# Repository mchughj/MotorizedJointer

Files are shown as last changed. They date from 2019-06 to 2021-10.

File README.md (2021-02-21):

# MotorizedJointer

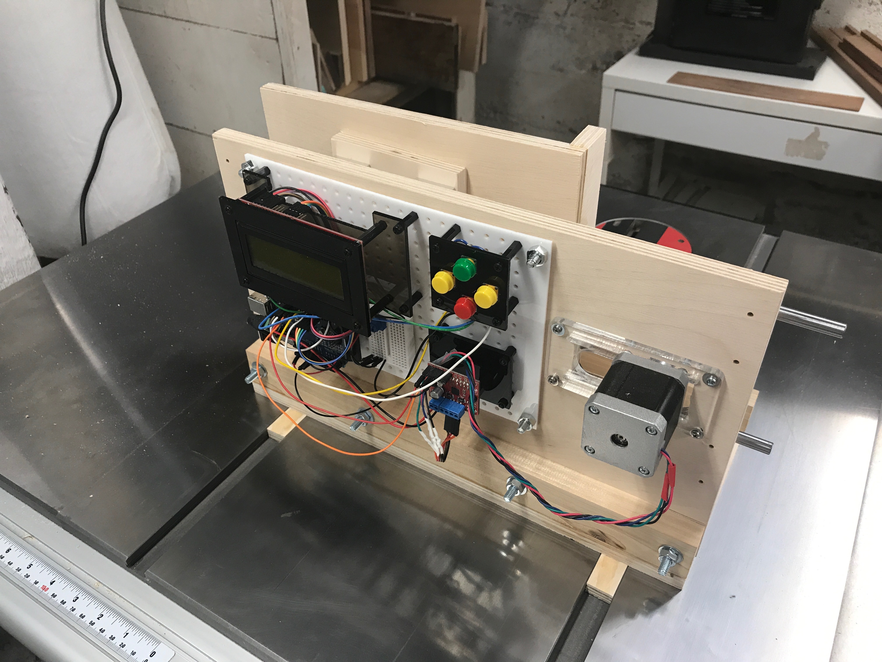
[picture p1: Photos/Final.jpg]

(Yes, wire management is not my strong suit.  But it works!)

This is a project which I started in 2017 after seeing a YouTube video on something similar.  

The main software appears in the CustomizableBoxCutter directory.

Hardware
 * A sparkfun "Basic 20x4 Character LCD - Black on Green 5V".  This is an HD47780-based display.  Retired version here: https://www.sparkfun.com/products/retired/256  
 * A Nema 17 stepper motor.  Example: https://www.sparkfun.com/products/9238  
 * A driver for the stepper motor.  I used a Big Easy Driver: https://www.sparkfun.com/products/12859
 * An arduino Uno.  Any Uno will do.
 * Four small buttons.  These will work: https://www.sparkfun.com/products/14460

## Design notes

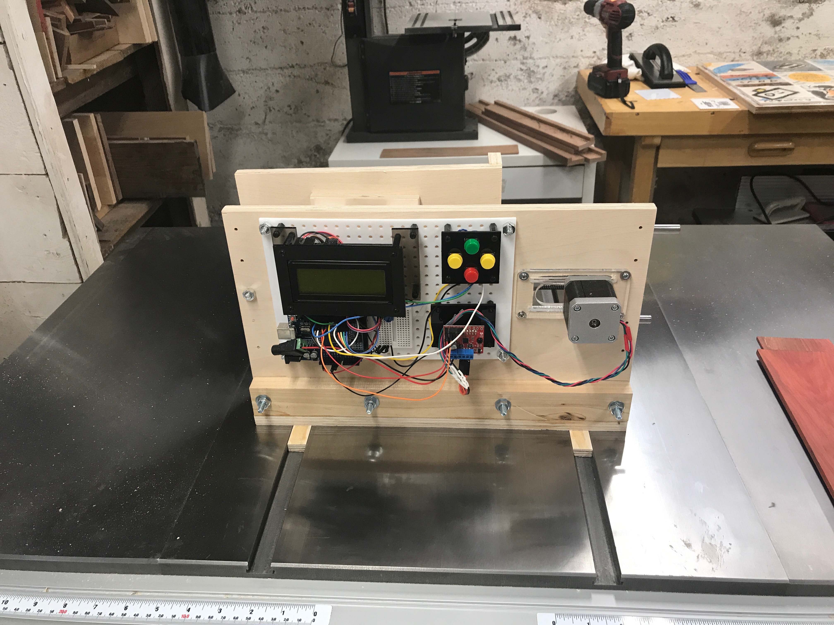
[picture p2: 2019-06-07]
Photos/BackView.jpg

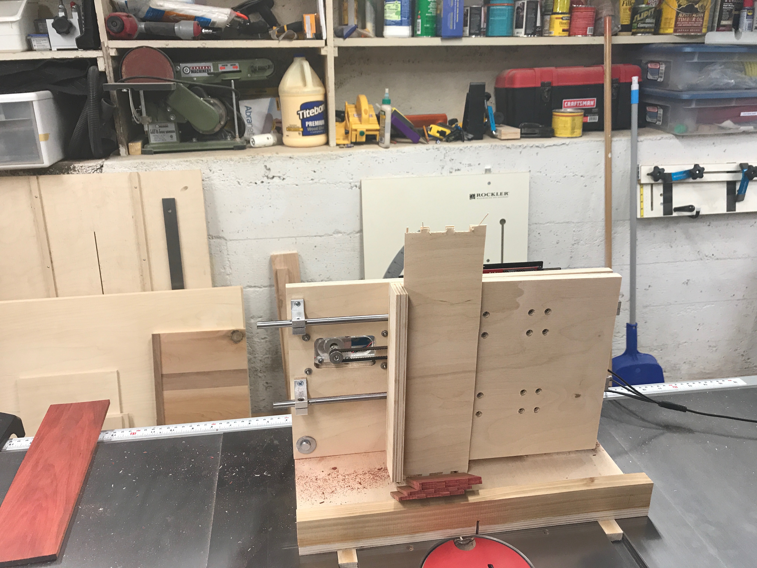
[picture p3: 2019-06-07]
Photos/FirstCuts.jpg

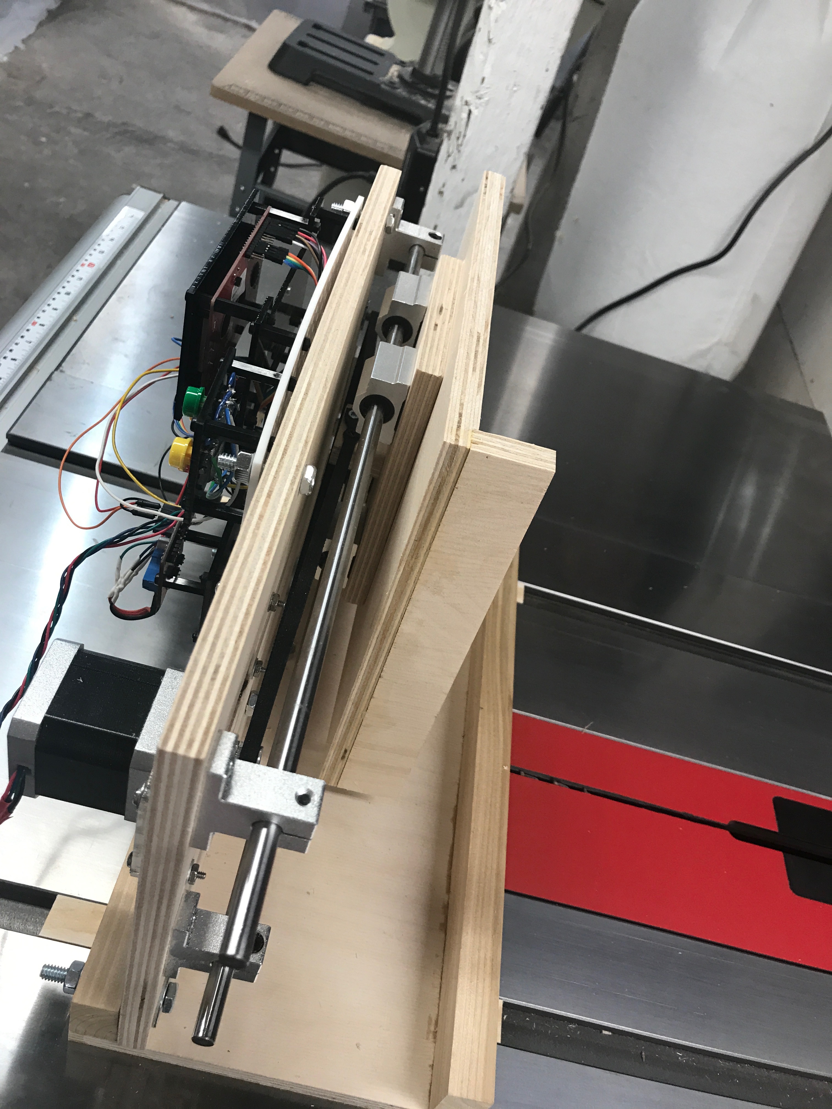
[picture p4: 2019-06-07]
Photos/SideView.jpg

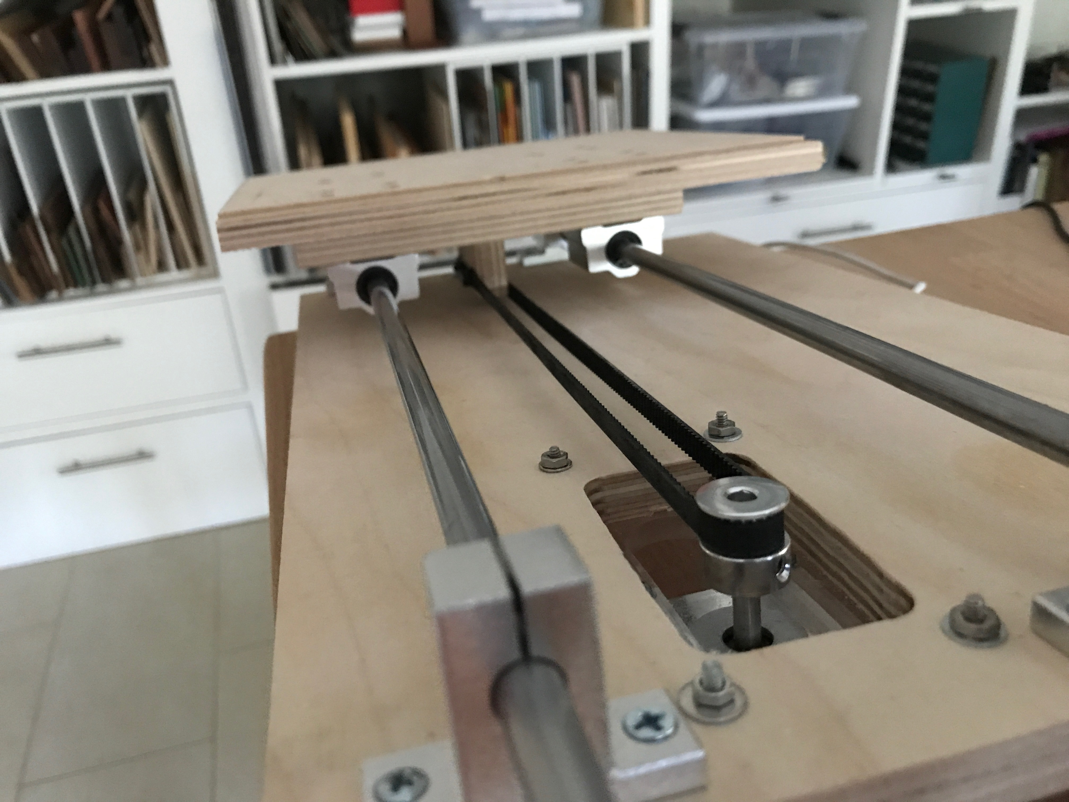
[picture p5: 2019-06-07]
Photos/Gantry.jpg

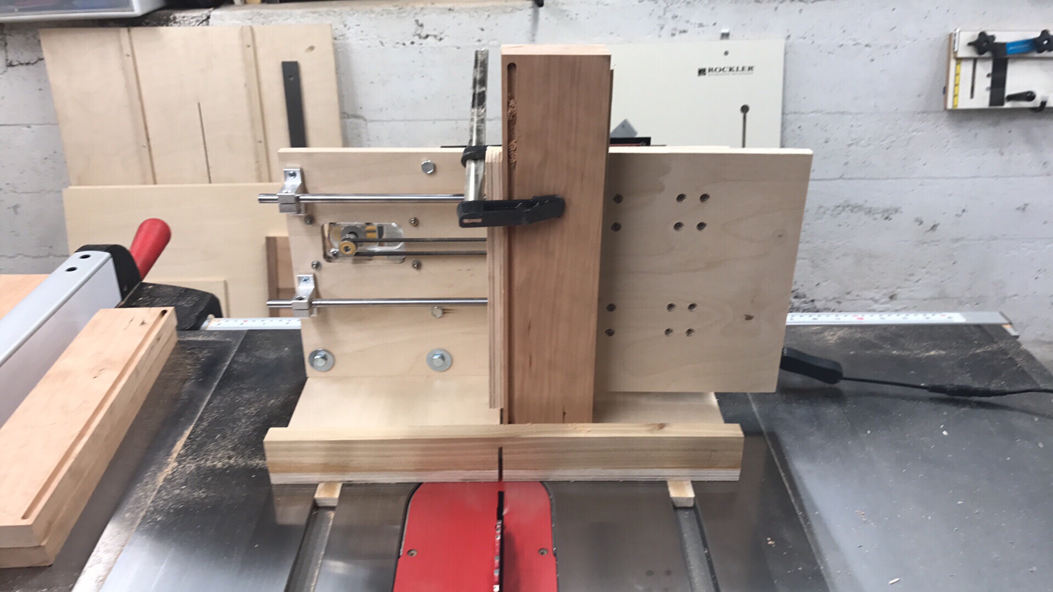
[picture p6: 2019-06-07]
Photos/LongCut.jpg

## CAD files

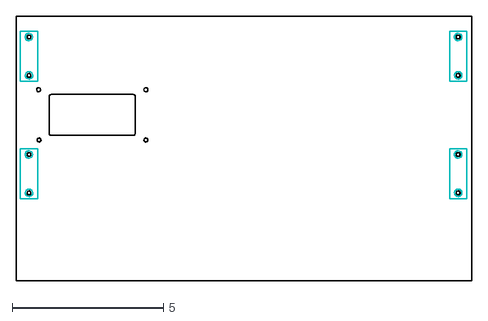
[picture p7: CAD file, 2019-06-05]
Hardware/Rails.dxf
15.0 x 8.75

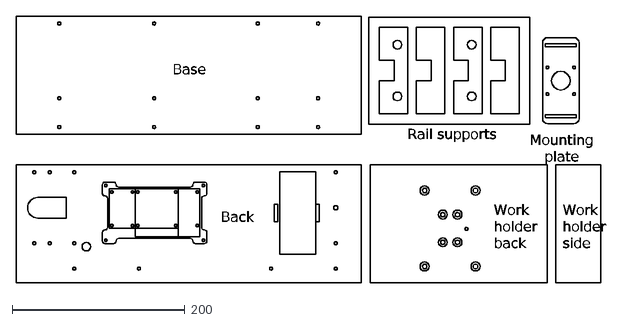
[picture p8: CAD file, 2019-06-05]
Hardware/sj_ply_manual.dxf
Work holder back
Rail supports
Work holder side
Base
Back
Mounting plate

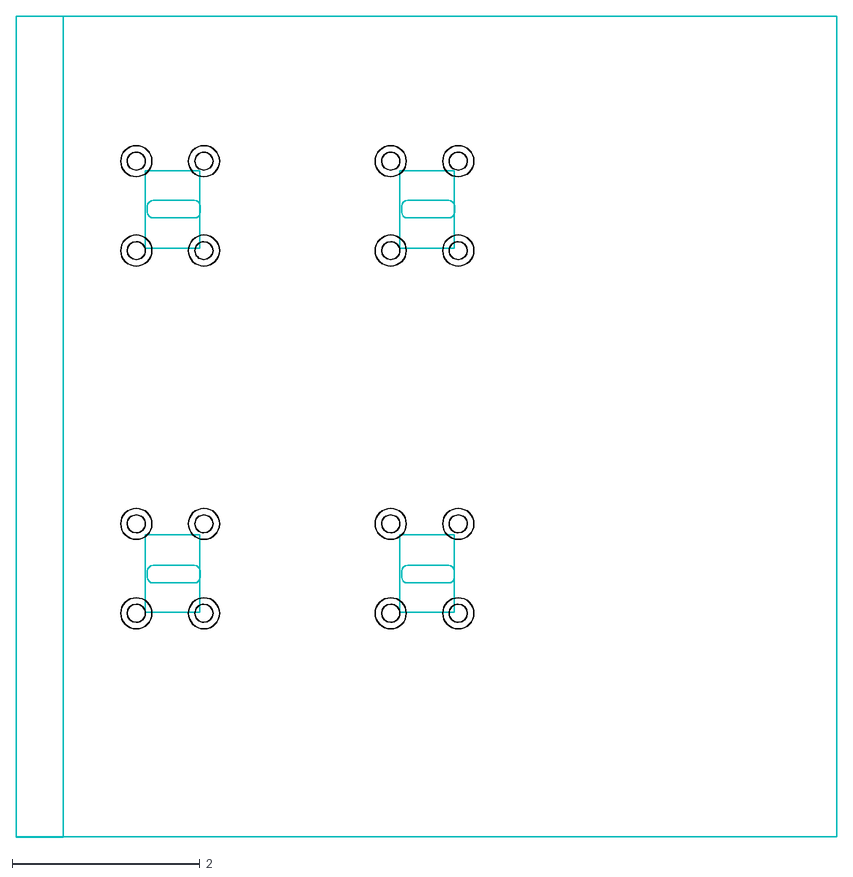
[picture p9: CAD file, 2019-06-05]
Hardware/Gantry.dxf
8.75 x 8.75

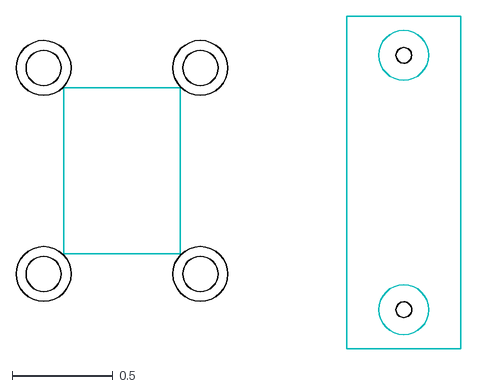
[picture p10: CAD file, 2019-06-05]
Hardware/LinearBearing.dxf
2.21 x 1.65

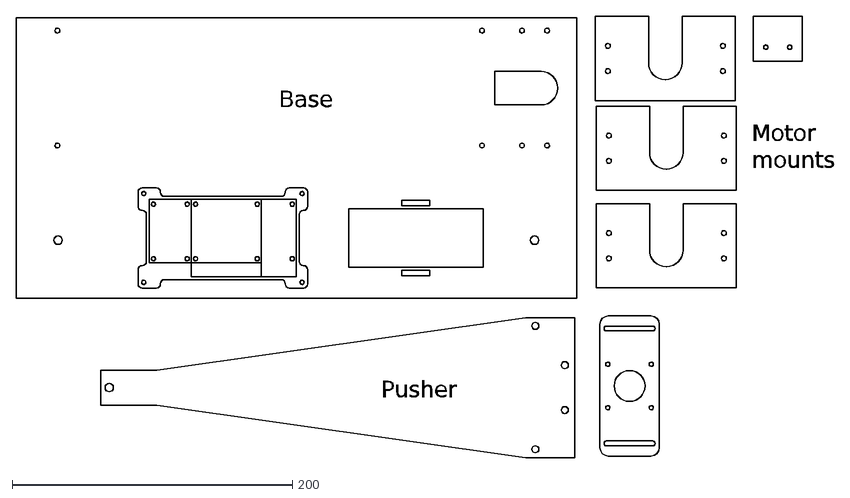
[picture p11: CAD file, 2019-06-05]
Hardware/sj_pusher.dxf
Base
Pusher
Motor mounts

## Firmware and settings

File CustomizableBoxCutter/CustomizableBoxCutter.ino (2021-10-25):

// This embedded program drives the behavior of the customizable box cutter.  
// This derives from, and expands up, the original 'simple box cutter'.
//
// 6/30/2019: First version

// Hardware:
// 1/  A sparkfun "Basic 20x4 Character LCD - Black on Green 5V".  This is
//     an HD47780-based display.  
// 2/  A Nema 17 stepper motor.  https://www.sparkfun.com/products/9238  
// 3/  A Big Easy Driver.  https://www.sparkfun.com/products/12859

// LCD Pins:
//
// LCD RS pin to digital pin 12
// LCD Enable pin to digital pin 11
// LCD D4 pin to digital pin 5
// LCD D5 pin to digital pin 4
// LCD D6 pin to digital pin 3
// LCD D7 pin to digital pin 2
// LCD R/W pin to ground
// LCD VSS pin to ground
// LCD VCC pin to 5V
// 
// Input pins:
//   6  - Left button
//   7  - Right button
//   8  - Center button
//
// Stepper Pins:
//   9  - Step
//   10 - Direction
//


// --------------------------------------------------------------------------
// Understanding the finger & valley goodness
// --------------------------------------------------------------------------

// This documentation is broken up into three sections where each 
// subsequent section builds on the prior and introduces some complexity
// that was glossed over in the prior section.  This aids in understanding
// what is happening into smaller sized chunks.
//
// Section 1:  Fingers & Valleys
// Section 2:  Initial cuts versus subsequent cuts
// Section 3:  Non-uniform sized cuts


// --------------------------------------------------------------------------
// Section 1:  Fingers & Valleys
// --------------------------------------------------------------------------

//
//  The Finger Joints look like this:
//
//        "Negative"              "Positive"
//    isCutFirst = False      isCutFirst = True
//    +------------------+    +---------------+
//    |     WOOD         |    |     WOOD      |
//    |                  |    |               |
//    |    [Finger]      |    |   [Valley]    |
//    |                  |    |               |
//    |          +-------+    |               |
//    |          |    +-------+               |
//    |          |    |                       |
//    | [Valley] |    |           [Finger]    |
//    |          |    |                       |
//    |          |    +-------+               |
//    |          +-------+    |               |
//    |                  |    |               |
//        ... 
//
// There are 2 values in use when you are doing a pair of Finger and Valley. 
// The first is how much to cut - this is the size of the valley.  The second
// is the amount to move giving you the size of the finger.
// The valley needs to be larger than the finger by just a little bit.
// If they were the exact same size then they would be too tight. 
// Depending on the material and the characteristics of the cutting, a few
// thousands of an inch should be sufficient.  This parameter (the additional
// thousandths of an inch to cut to allow them to fit) is called 'slop'.
//
// The units for all variables that are capturing distance are in thousandths
// of an inch.  So 500 is 0.5 inches.

// The menu on the device talks about "Positive" and "Negative" for the two
// mating pieces of wood. 
// 
//  When "Positive" then isCutFirst = True - which means we cut then move:
//    distanceRemainingToCut = initialDTMValley;
//    distanceRemainingToMove = subDTMFinger;
//

//
//  When "Negative" then isCutFirst = False - which means that we just move:
//    distanceRemainingToCut = 0;
//    distanceRemainingToMove = initialDTMFinger;
//



// --------------------------------------------------------------------------
// Section 2:  Initial cuts versus subsequent cuts
// --------------------------------------------------------------------------

// Positive and negative cuts are all good but how do we make the entire
// process repeatable given that we don't want to create an initial setup 
// that is simple and doesn't require any guess work on where to start?
//

// The jig is operated by the following steps:
//   0/  Clamp the wood into the gantry.  Make sure it is flush and square.
//   1/  Move the gantry (not the wood) so that the wood is flush against 
//       the table saw.
//   2/  Select the cut type, turn on the table saw.
// 
//   3/  Push the jig forward, then back.
//   4/  Hit the next button (on the right) on the jig.
//   5/  Goto step 2.
//  
// This keeps the process simple and repeatable.  Two important characteristics
// when moving wood over-and-over through a spinning blade!!
// 

// But this also complicates the software as we need to get the movement and
// cut values correct given that there are two situations.  This is because on
// the very first finger/valley the blade is to the left of where the wood is.
// To start the wood is put flush against the blade and, when we push the jig
// through the blade (step #3), empty air is cut.  The setup looks like this:
//
//  
//            B                             ^      
//            L                             |
//            A                             |
//       ----+D                        Human Pushes
//           |E                          the jig
//           |                              |
//           |                              |
//
//   -> Stepper movement ->
// 
// When you push the jig forward, and move the blade through the wood, 
// no wood is actually cut since the initial setup has the blade flush against
// the wood.
//

// This requires the 'initial' finger (or valley) to differ from all others
// because the kerf distance needs to be taken into account.
//
// For the first finger/valley, the variables 'initialDTMFinger' or
// 'initialDTMValley' are used.  DTM stands for 'distance to move'.  
//
//    initialDTMValley  =  valleySize     +  slop         +  0;  
//    initialDTMFinger  =  fingerSize     +  -slop        +  kerf;  
//
// Because step #3 doesn't actually do anything (you cut empty air the first
// time) the initial distance to cut includes the full slot and slop.  The zero
// term there will make sense once you see the subDTMValley for non-initial
// finger/valleys.
//
// The initialDTMFinger is offset by the kerf term in order to position
// the cutter inside of the wood for the next step.

// 
// After that first initial finger or valley the blade is ready to pass through
// material into the valley of the second and all subsequent joints.  This is
// because when doing a negative cut we don't do anything but move to the
// starting point of the first valley.  When doing positive then we cut and
// then do a big move.  In both cases we are ready to pass the material through
// the blade as part of the subsequent valley.
//
// In this case the setup looks like this:
//  
//                -> Stepper movement ->
// 
//            B                           B              
//            L                           L                      ^ 
//            A                           A                      | 
//            D                           D                      | 
//            E              OR           E                 Human Pushes
//      +--------                   +-----------              the jig
//      |                           |                            |
//      |                           |                            |
//  +---+                           |             
//  |                               |         
//   
//
// Now step #3 will *not* cut empty air.  It will cut a kerf amount of wood.  
// Therefore all subsequent valley and finger distance to moves are 
// defined by:
//  
//    subDTMValley  = valleySize     +  slop         -  kerf;  
//    subDTMFinger  = fingerSize     +  -slop        +  kerf;
// 
// The term 'sub' is short for subsequent which captures all fingers and
// valleys after the first.


// --------------------------------------------------------------------------
// Section 3:  Non-uniform sized cuts
// --------------------------------------------------------------------------
//
// Final complication!  When you are doing the same sized fingers and 
// valleys then the process is simple.  When doing variable sized fingers
// and valleys the conceptual is still the same but the details are a
// bit more tricky.  
//                                              
// When doing the programmatic cut you set the individual stop points for
// each of the fingers or valleys.  Whether the stop point represents a 
// finger or valley depends upon whether you are doing the positive or
// negative piece.
//
// The numeric values shown below are the thous that have been set up 
// while programming.  
// 
//        Negative              Positive
//    +-----------------+    +---------------+
//    |                 |    |               |
//    | 200             |    |    200        |
//    |     Wood        |    |               |
//    |                 |    |               |
//    |         +-------+    |               |
//    |         |    +-------+               |
//    | 300     |    |                       |
//    |         |    |            300        |
//    |         |    |                       |
//    |         |    +-------+               |
//    |         +-------+    |               |
//    |                 |    |               |
//    |                 |    |               |
//    |                 |    |               |
//    | 500             |    |   500         |
//    |                 |    |               |
//    |                 |    |               |
//    |         +-------+    |               |
//    |         |    +-------+               |
//    | 300     |    |                       |
//    |         |    |           300         |
//    |         |    |                       |
//    |         |    +-------+               |
//    |         +-------+    |               |
//    |                 |    |               |
//    |                 |    |               |
//    | 200             |    |   200         |
//    |                 |    |               |
//    +-----------------+    +---------------+
// 
// In the example above the programmaticSlots would look like:
//  programmaticSlots[] = {
//     200,
//     300,
//     500,
//     300,
//     200,
//     0, 0, 0, ..., 0,
//  }
// 
// When doing the positive we would pass in 
//  valley = 200 (programmaticSlot[0]), finger = 300 (programmaticSlots[1])
//  valley = 500 (programmaticSlot[2]), finger = 300 (programmaticSlots[3])
//  valley = 200 (programmaticSlot[4]), finger = 200 (programmaticSlots[0])
//    (If the end of the piece of wood is reached before wrapping around 
//       then the wrap around doesn't matter.)
// 
// When doing the negative we would pass in 
//  valley = 0 (no programmaticSlot!),  finger = 200 (programmaticSlots[0])
//  valley = 300 (programmaticSlot[1]), finger = 500 (programmaticSlots[2])
//  valley = 300 (programmaticSlot[3]), finger = 200 (programmaticSlots[4])
//
// Thus the movement through the programmaticSlots is always by 2s for 
// a single valley and finger pair, but it is offset by one when 
// doing the negative.  

 
#include <LiquidCrystal.h>
#include <EEPROM.h>   

#define BUTTON_LEFT_PIN 6
#define BUTTON_RIGHT_PIN 7
#define BUTTON_DOWN_PIN 8
#define BUTTON_UP_PIN 13
#define STEP_PIN 10
#define DIRECTION_PIN 9
#define MOTOR_ENABLE_PIN A0
#define MOTOR_MS1_PIN A3
#define MOTOR_MS2_PIN A4
#define MOTOR_MS3_PIN A5

// All units are in thousands of an inch.
// So, for example, 125 = 0.125"

// Default kerf size of blade
uint16_t kerf = 123;

// Default movement can be less than the kerf of the blade if you want overlapping cuts.
uint16_t maxAdvance = 100;

#define MAX_PROGRAMMATIC_SLOTS 64
uint16_t uniformSlot;
uint16_t programmaticSlots[MAX_PROGRAMMATIC_SLOTS] = {
       125, 125, 125, 125, 125, 125, 125, 125,
       125, 125, 125, 125, 125, 125, 125, 125,
       125, 125, 125, 125, 125, 125, 125, 125,
       125, 125, 125, 125, 125, 125, 125, 125,
       0,   0,   0,   0,   0,   0,   0,   0,
       0,   0,   0,   0,   0,   0,   0,   0,
       0,   0,   0,   0,   0,   0,   0,   0,
       0,   0,   0,   0,   0,   0,   0,   0,
};
uint16_t programmaticIndex = 0;
uint16_t slop = 1;

// Computed based on the current options.  Set in determineMovementValues.
// DTM == Distance To Move.
uint16_t initialDTMValley;
uint16_t initialDTMFinger;
uint16_t subDTMValley;
uint16_t subDTMFinger;

uint16_t currentFingerSize;
uint16_t currentValleySize;

uint16_t distanceRemainingToCut = 0;
uint16_t distanceRemainingToMove = 0;

// Default speed for movement.  This is in microseconds and captures the amount of time
// to wait inbetween low and high pulses.  A larger number indicates slower speed.
uint16_t motorSpeed = 500;

// Default length of wood and number of slots.
uint32_t lengthOfWood = 4000;
uint16_t numberOfSlots = 6;

// Initialize the LCD.  Pin numbers in the below match the earlier comments.
LiquidCrystal lcd(12, 11, 5, 4, 3, 2);

// Creating characters for display is pretty straightforward.
// Use this site:  http://www.quinapalus.com/hd44780udg.html
// for all of the heavy lifting.
byte thumbUpIcon[6][8] = {
 {B00100,B00011,B00100,B00011,B00100,B00011,B00010,B00001},
 {B00000,B00000,B00000,B00000,B00000,B00000,B00000,B00011},
 {B00000,B00000,B00000,B00000,B00000,B00000,B00001,B11110},
 {B00000,B01100,B10010,B10010,B10001,B01000,B11110,B00000},
 {B00010,B00010,B00010,B00010,B00010,B01110,B10000,B00000},
 {B00000,B00000,B00000,B00000,B00000,B10000,B01000,B00110}
};

#define MAIN_MENU 0
#define CUT_MENU 1
#define CONFIG_MENU 3
#define CONFIG_CHANGE_VALUE_MENU 4
#define UNIFORM_CUT_MENU 5
#define PROGRAMMATIC_CUT_MENU 6
#define CUT_TYPE_MENU 7

void registerThumbUp() { 
  for( int i=0; i < 6; i++ ) { 
    lcd.createChar(i, thumbUpIcon[i]);
  }
}

bool isLeftButtonPressed() {
  return digitalRead( BUTTON_LEFT_PIN ) == LOW;
}

bool isRightButtonPressed() {
  return digitalRead( BUTTON_RIGHT_PIN ) == LOW;
}

bool isDownButtonPressed() {
  return digitalRead( BUTTON_DOWN_PIN ) == LOW;
}

bool isUpButtonPressed() {
  return digitalRead( BUTTON_UP_PIN ) == LOW;
}

void waitForButtonRelease(uint8_t pin) { 
  delay(50);
  while( digitalRead(pin) == LOW ) { 
    delay(1);
  }
  delay(40);
}
void waitForLeftButtonRelease() {
  waitForButtonRelease(BUTTON_LEFT_PIN);
}

void waitForDownButtonRelease() {
  waitForButtonRelease(BUTTON_DOWN_PIN);
}

void waitForRightButtonRelease() {
  waitForButtonRelease(BUTTON_RIGHT_PIN);
}

void waitForUpButtonRelease() {
  waitForButtonRelease(BUTTON_UP_PIN);
}

void motorOn() {
  digitalWrite(MOTOR_ENABLE_PIN, LOW); 
}

void motorOff() {
  digitalWrite(MOTOR_ENABLE_PIN, HIGH);
}

void stepMotor(uint16_t d = motorSpeed) { 
  digitalWrite(STEP_PIN, HIGH);
  delayMicroseconds(d);
  digitalWrite(STEP_PIN, LOW);
  delayMicroseconds(d);
}

bool moveStepper(uint16_t thousDistance, bool isLeft) { 
  if( isLeft ) { 
    digitalWrite(DIRECTION_PIN, LOW);
  } else {
    digitalWrite(DIRECTION_PIN, HIGH);
  }

  // The number of steps per thousandths of an inch
  float stepsPerThou = 4.19;
  unsigned long int numberOfSteps = ceil(( ( (unsigned long int) thousDistance) * stepsPerThou ));
  Serial.print(F("moveStepper; inches: " ));
  Serial.print(thousDistance);
  Serial.print(F(", isLeft: " ));
  Serial.print(isLeft);
  Serial.print(F(", numberOfSteps: " ));
  Serial.println(numberOfSteps);
  for( unsigned long int i = 0; i < numberOfSteps; i++ ) { 
    stepMotor();
  }
  return true;
}

void drawThumbUp() { 
  lcd.setCursor(16,3);
  lcd.write((uint8_t)0);
  lcd.setCursor(16,2);
  lcd.write((uint8_t)1);
  lcd.setCursor(17,3);
  lcd.write((uint8_t)2);
  lcd.setCursor(17,2);
  lcd.write((uint8_t)3);
  lcd.setCursor(18,3);
  lcd.write((uint8_t)4);
  lcd.setCursor(18,2);
  lcd.write((uint8_t)5);
}

void writeSettings() {
  uint8_t kerfInByte = (uint8_t) kerf;

  Serial.print( F("going to writeSettings; kerf: "));
  Serial.print(kerf);
  Serial.print( F(", motorSpeed: "));
  Serial.print(motorSpeed);
  Serial.print( F(", slop: "));
  Serial.print(slop);
  Serial.print( F(", lengthOfWood: "));
  Serial.print(lengthOfWood);
  Serial.print( F(", numberOfSlots: "));
  Serial.print(numberOfSlots);
  Serial.print( F(", maxAdvance: "));
  Serial.print(maxAdvance);
  Serial.print( F(", uniformSlot: "));
  Serial.println(uniformSlot);
  
  EEPROM.write(0, byte(215));
  EEPROM.write(1, byte(kerf));
  EEPROM.write(2, byte(motorSpeed / 256));
  EEPROM.write(3, byte(motorSpeed % 256));
  EEPROM.write(4, byte(slop / 256));
  EEPROM.write(5, byte(slop % 256));

  EEPROM.put(6, lengthOfWood);

  EEPROM.write(10, byte(numberOfSlots / 256));
  EEPROM.write(11, byte(numberOfSlots % 256));

  EEPROM.write(12, byte(maxAdvance));

  EEPROM.write(13, byte(uniformSlot / 256));
  EEPROM.write(14, byte(uniformSlot % 256));

  for( int i=0; i < MAX_PROGRAMMATIC_SLOTS; i++ ) { 
    EEPROM.write(15 + (i*2), byte(programmaticSlots[i] / 256));
    EEPROM.write(16 + (i*2), byte(programmaticSlots[i] % 256));
  }

  Serial.print( F("Programmatic slots, maxLength: "));
  Serial.print( MAX_PROGRAMMATIC_SLOTS );
  for( int i=0; i < MAX_PROGRAMMATIC_SLOTS; i++ ) { 
    Serial.print( F(", S" ));
    Serial.print( i );
    Serial.print( F(": "));
    Serial.print(programmaticSlots[i]);
  }
  Serial.println( F("!"));

  lcd.setCursor(1, 1);
  lcd.print("Saved settings");
  delay(1000);
}

void determineMovementValues( uint16_t valleySize, uint16_t fingerSize ) {
  // Put the valley and finger sizes in a global variable for the 
  // display to easily access.
  currentValleySize = valleySize;
  currentFingerSize = fingerSize;

  // See comments at the top of the file.
  initialDTMValley  =  valleySize   +  slop    + 0;  
  initialDTMFinger  =  fingerSize   + -slop    + kerf; 

  subDTMValley      =  valleySize   +  slop    + -kerf;
  subDTMFinger      =  fingerSize   + -slop    + kerf;
}


void readSettings() {
  byte kerfByte = EEPROM.read(1);
  kerf = kerfByte;
  
  motorSpeed = (EEPROM.read(2) * 256) + EEPROM.read(3);
  slop = (EEPROM.read(4) * 256) + EEPROM.read(5);

  EEPROM.get(6, lengthOfWood);

  numberOfSlots = (EEPROM.read(10) * 256) + EEPROM.read(11);

  byte maxAdvanceByte = EEPROM.read(12);
  maxAdvance = maxAdvanceByte;

  uniformSlot = (EEPROM.read(13) * 256) + EEPROM.read(14);

  for( int i=0; i < MAX_PROGRAMMATIC_SLOTS; i++ ) { 
    uint16_t s = (EEPROM.read(15 + (i * 2)) * 256) + EEPROM.read(16 + (i*2));
    programmaticSlots[i] = s;
  }

  Serial.print( F("read in the settings; kerf: "));
  Serial.print(kerf);
  Serial.print( F(", motorSpeed: "));
  Serial.print(motorSpeed);
  Serial.print( F(", slop: "));
  Serial.print(slop);
  Serial.print( F(", lengthOfWood: "));
  Serial.print(lengthOfWood);
  Serial.print( F(", numberOfSlots: "));
  Serial.print(numberOfSlots);
  Serial.print( F(", maxAdvance: "));
  Serial.print(maxAdvance);
  Serial.print( F(", uniformSlot: "));
  Serial.print(uniformSlot);

  for( int i=0; i < MAX_PROGRAMMATIC_SLOTS; i++ ) { 
    Serial.print( F(", S" ));
    Serial.print( i );
    Serial.print( F(": "));
    Serial.print(programmaticSlots[i]);
  }
  Serial.println("!");
}


void setup() {
  Serial.begin(9600);
  Serial.println("In setup");
  Serial.println( __DATE__ " " __TIME__ );
  pinMode( STEP_PIN, OUTPUT );
  pinMode( DIRECTION_PIN, OUTPUT ); 
  
  pinMode( BUTTON_LEFT_PIN, INPUT_PULLUP );
  pinMode( BUTTON_RIGHT_PIN, INPUT_PULLUP );
  pinMode( BUTTON_DOWN_PIN, INPUT_PULLUP );
  pinMode( BUTTON_UP_PIN, INPUT_PULLUP );

  pinMode( MOTOR_ENABLE_PIN, OUTPUT );

  pinMode( MOTOR_MS1_PIN, OUTPUT);
  pinMode( MOTOR_MS2_PIN, OUTPUT);
  pinMode( MOTOR_MS3_PIN, OUTPUT);
  digitalWrite( MOTOR_MS1_PIN, HIGH ); 
  digitalWrite( MOTOR_MS2_PIN, HIGH );
  digitalWrite( MOTOR_MS3_PIN, HIGH );
  
  lcd.begin(20, 4);
  registerThumbUp();

  // If the eeprom on the arduino doesn't have settings stored there or
  // if you hold the up button when you turn on the unit, then we write 
  // the default values.
  if (EEPROM.read(0) != 215 || isUpButtonPressed()) { 
    Serial.println("Writing configuration setup");
    writeSettings(); 
    readSettings();
  } else {
    Serial.println("Reading configuration setup");
    readSettings();
  }
  Serial.println("Done with setup");
}

void showOptions(const char *left, const char *bottom, const char *right = NULL, const char *top = NULL, const int startLine = 1) { 
  char statusMessage[16];

  if( top ) { 
    showCentered(top, startLine);
  }
  if( left ) {
    snprintf(statusMessage, 16, "%s", left);
    lcd.setCursor(0, startLine+1);
    lcd.print(statusMessage);
  }
  if( right ) {
    showRightAligned(right, startLine+1);
  }
  if( bottom ) {
    showCentered(bottom, startLine+2);
  }
}

int state = 0;
bool isUniformCut = true;
int pos = 0;
bool refreshDisplay = true;

bool isCutFirst = true;

void setupForCut( bool cutFirst ) {
  motorOn();

  isCutFirst = cutFirst;
  
  if( isCutFirst ) { 
    distanceRemainingToCut = initialDTMValley;
    distanceRemainingToMove = subDTMFinger;
  } else {
    distanceRemainingToCut = 0;
    distanceRemainingToMove = initialDTMFinger;
  }
}
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
void loop() {
  if (state == MAIN_MENU) { 
    showMainMenu();
  } else if (state == CUT_MENU) {     
    showCutMenu();
  } else if (state == CONFIG_MENU) {
    showConfigMenu();
  } else if (state == CONFIG_CHANGE_VALUE_MENU) {
    showConfigChangeValueMenu();
  } else if (state == CUT_TYPE_MENU) {
    showCutTypeMenu();
  }
}

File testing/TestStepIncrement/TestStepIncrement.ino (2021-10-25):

//
// 10/22/2021
//
// After questioning the accuracy of the jig in terms of distance
// moved I decided to make a more robust measurement of the 
// distance traveled.  I also wanted to make sure that I was moving
// the smallest possible distance with every pulse.  As it turns
// out though the Sparkfun "Big Easy Driver" defaults to 1/16th steps
// when you don't access the MS1, MS2 and MS3 pins.  (They are 
// all tied high by default.)
//
// Using a Dial Indicator (https://www.amazon.com/gp/product/B002YPHT76/)
// I measured the precise thousands of an inch that the device
// moved over multiple distances to get - as close as I could determine -
// the number of steps required to move one thousandth of an inch.
//
// This script assumes you are using the big easy driver by sparkfun:
// https://www.sparkfun.com/products/12859
//


#define STEP_PIN 10
#define DIRECTION_PIN 9
#define ENABLE_PIN A0
#define MS1 A3
#define MS2 A4
#define MS3 A5

uint16_t motorSpeed = 500;
bool enabled = true;


void stepMotor(uint16_t d = motorSpeed) { 
  digitalWrite(STEP_PIN, HIGH);
  delayMicroseconds(d);
  digitalWrite(STEP_PIN, LOW);
  delayMicroseconds(d);
}

void moveStepper(int numberOfSteps, int directionValue = LOW, int ms1Value = LOW, int ms2Value = LOW, int ms3Value = LOW) {
  digitalWrite(MS1, ms1Value);
  digitalWrite(MS2, ms2Value);
  digitalWrite(MS3, ms3Value);
  digitalWrite(DIRECTION_PIN, directionValue);
  
  for( int i = 0; i < numberOfSteps; i++ ) { 
    stepMotor();
 }
}

int thousToSteps(int thous) { 
   float steps = thous * 4.19;
   
   return ceil(steps);
}

void resetMotorPins()
{
  digitalWrite(STEP_PIN, LOW);
  digitalWrite(DIRECTION_PIN, LOW);
  digitalWrite(MS1, LOW);
  digitalWrite(MS2, LOW);
  digitalWrite(MS3, LOW);

  if (enabled) { 
    digitalWrite(ENABLE_PIN, LOW);
  } else {
    digitalWrite(ENABLE_PIN, HIGH);
  }
}

void setup() {
  Serial.begin(9600);
  Serial.println("In setup");
  Serial.println( __DATE__ " " __TIME__ );
  pinMode(STEP_PIN, OUTPUT );
  pinMode(DIRECTION_PIN, OUTPUT); 
  pinMode(MS1, OUTPUT);
  pinMode(MS2, OUTPUT);
  pinMode(MS3, OUTPUT);
  pinMode(ENABLE_PIN, OUTPUT);

  resetMotorPins(); 
  
  Serial.println("Begin motor test");
  Serial.println();
  //Print function list for user selection
  Serial.println("Enter number for control option:");
  Serial.println("1. Turn at 1/8th microstep mode.");
  Serial.println("2. Reverse direction at 1/8th microstep mode.");
  Serial.println("3. Turn at 1/16th microstep mode.");
  Serial.println("4. Reverse turn at 1/16th microstep mode.");
  Serial.println("5. Toggle enable of motor.");
  Serial.println("6. Move forward 0.25 inches");
  Serial.println("7. Move backwards 0.25 inches");
  Serial.println("8. Increase distance to travel.");
  Serial.println("9. Decrease distance to travel.");
  Serial.println();
}

int distance_to_move = 500;

// 500 is 0.17"

void loop() {
  int available;
  while(available = Serial.available()) {
      Serial.print( "Bytes waiting for me: ");
      Serial.println(available);
      char user_input = Serial.read(); //Read user input and trigger appropriate function

      if (available > 1) {
        int additional = 1;
        while (additional < available) { 
          Serial.print( "Additional data: ");
          Serial.println( Serial.read());
          additional += 1; 
        }
      }
      
      if (user_input =='1')
      {
         Serial.println( "Moving stepper forward 1/8th step");
         moveStepper(distance_to_move, LOW, HIGH, HIGH, LOW);

         if (!enabled) { 
           Serial.println( "Enable is off; suppressing action." );
         }
      }
      else if(user_input =='2')
      {
         Serial.println( "Moving stepper backward 1/8th step");
         moveStepper(distance_to_move, HIGH, HIGH, LOW, LOW);
         
         if (!enabled) { 
           Serial.println( "Enable is off; suppressing action." );
         }
      }
      else if(user_input =='3')
      {
          Serial.println( "Moving stepper forward 1/16th step");
          moveStepper(distance_to_move, LOW, HIGH, HIGH, HIGH);         
          if (!enabled) { 
            Serial.println( "Enable is off; suppressing action." );
          }
      }
      else if(user_input =='4')
      {
          Serial.println( "Moving stepper backward 1/16th step");
          moveStepper(distance_to_move, HIGH, HIGH, HIGH, HIGH);         
          if (!enabled) { 
           Serial.println( "Enable is off; suppressing action." );
         }
      }
      else if(user_input == '5') 
      {
         Serial.print( "Changing enabled pin;  motors active: ");
         enabled = !enabled;
         if (enabled) { 
            Serial.println( "Yes");
         } else {
            Serial.println( "No");
         }
      } 
      else if(user_input == '6') { 
        int steps = thousToSteps(250);
        Serial.print( "Moving stepper forward 0.25 inches: ");
        Serial.println( steps);
        moveStepper(steps, LOW, HIGH, HIGH, HIGH);

         if (!enabled) { 
           Serial.println( "Enable is off; suppressing action." );
         }
      }
      else if(user_input == '7') {
        int steps = thousToSteps(250);
        Serial.print( "Moving stepper backward 0.25 inches: ");
        Serial.println( steps);
        moveStepper(steps, HIGH, HIGH, HIGH, HIGH);

        if (!enabled) { 
           Serial.println( "Enable is off; suppressing action." );
        }
      }
       else if(user_input == '8') { 
        distance_to_move += 100;
        Serial.print( "Distance to move is now: ");
        Serial.println(distance_to_move);
      }
      else if(user_input == '9') { 
        distance_to_move -= 100;
        Serial.print( "Distance to move is now: ");
        Serial.println(distance_to_move);
      }
      else
      {
        Serial.print("Invalid option entered;  read: '");
        Serial.print(user_input);
        Serial.println("'");
        Serial.println("Ensure serial mode has no newline enabled!");
      }
      resetMotorPins();
  }
}

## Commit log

2019-06-05 Moving into github
    [Gantry.dxf, LinearBearing.dxf, Rails.dxf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]
2019-06-06 Length of Wood and number of slots
    A large improvement in code refactoring, comments and clarity.
    Also added the ability to specify the length of the wood to be joined along with a number of slots. This will determine the size of each slot which should make it easier to get a nicely finished result when the size of the wood is fixed.
    [Character_generator.ino, SimpleBoxCutter.ino, TestStepIncrement.ino]
2019-06-13 Support for maxAdvance
    Main improvement here is to allow a 'maxAdvance' which can be smaller than the kerf size. This allows for multiple cuts over cleared out areas to remove any fuzzies or bent wood due to dull blades or softer woods.
    [SimpleBoxCutter.ino]
2019-06-17 All fingers same size, comments and refactor
    Prior to this change the first finger/valley was larger than the others due to inconsistency with how we were handling them. This is fixed, code has been refactored, and comments make it ultra clear what is actually happening.
    This change also renames the variables to make the semantics more precise. This is important to reflect what is actually happening and ensure that future errors (like the one fixed here) are avoided. Had I named the variables more precisely, relative to what they were actually doing, then the bug fixed here likely would have been avoided.
    [SimpleBoxCutter.ino]
2019-08-05 Fixed bugs with programmatic slots
    Added a ton of comments here to fully explain what happens with programmatic slots and fixed the code the offset the postive and negative correctly.
    [CustomizableBoxCutter.ino]
2021-10-25 Better memory usage, examples, and stepsPerThou
    Main change here is to make the stepsPerThou be a more accurate 4.19. Yes, floating point math on an Arduino! Also utilizing the F() call for better memory characteristics and changed a few examples 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
